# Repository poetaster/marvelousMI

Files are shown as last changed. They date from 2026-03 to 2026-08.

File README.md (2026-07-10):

## Introduction

marvelousMI is a fritzing project and PCB gerbers for a small desktop Mutable Instruments synth for use with the arduinoMI libraries. 

https://github.com/poetaster/arduinoMI

The 'marvelous' version is a eurorack version with slightly different ADC input handling (voltage dividers instead of diode clamps).

This is a basic circuit around an Olimex Pico2-xxl using a pcm5102 DAC for audio.

The firmware directory includes a complete synth with 3 parts:
* MI braids
* MI plaits
* MI rings

It's WIP but fully functional with midi and cv input.

More details and example audio and video can be found on my website at https://poetaster.org/marvelous

## Building with the arduino ide

I'm still using 1.8.19 because the behaviour of includes changed so much that it's easier just to stick to it. Some users have made adjustments to the lib to get them to compile, but the form in the repos is 1.8.19 compatible.

To build the ino you will need:

Into the arduino library context (on linux ~/Arduino/libraries) clone the individual modules:
https://github.com/poetaster/STMLIB
https://github.com/poetaster/PLAITS
https://github.com/poetaster/BRAIDS
https://github.com/poetaster/RINGS

In the STMLIB and PLAITS directories you will need to check out explicit branches:

git checkout plaits1.2 in both those directories.

You also need a couple of other libraries that you can install with the arduino ide:

Bounce2
pio_encoder
RotaryEncoder (I'm working with the raspberry pi guys on it).
Adafruit_SSD1306

with that done you should be able to compile / install directly to a marvelous or your own version thereof.

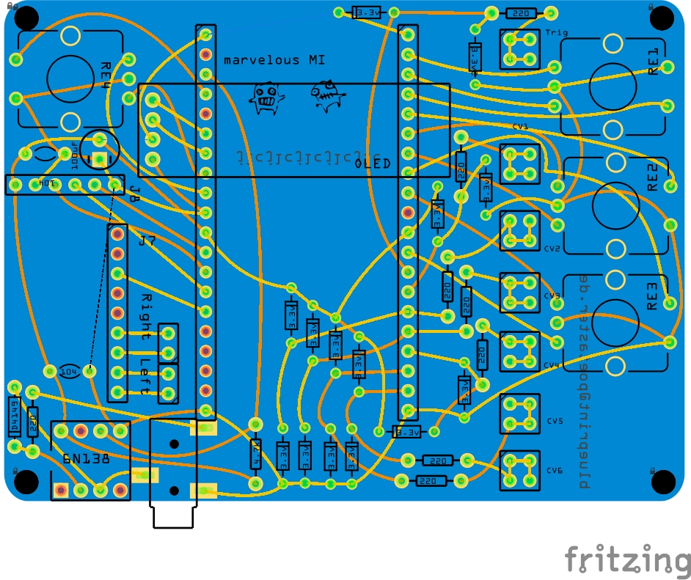
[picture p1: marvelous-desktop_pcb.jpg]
pcb view

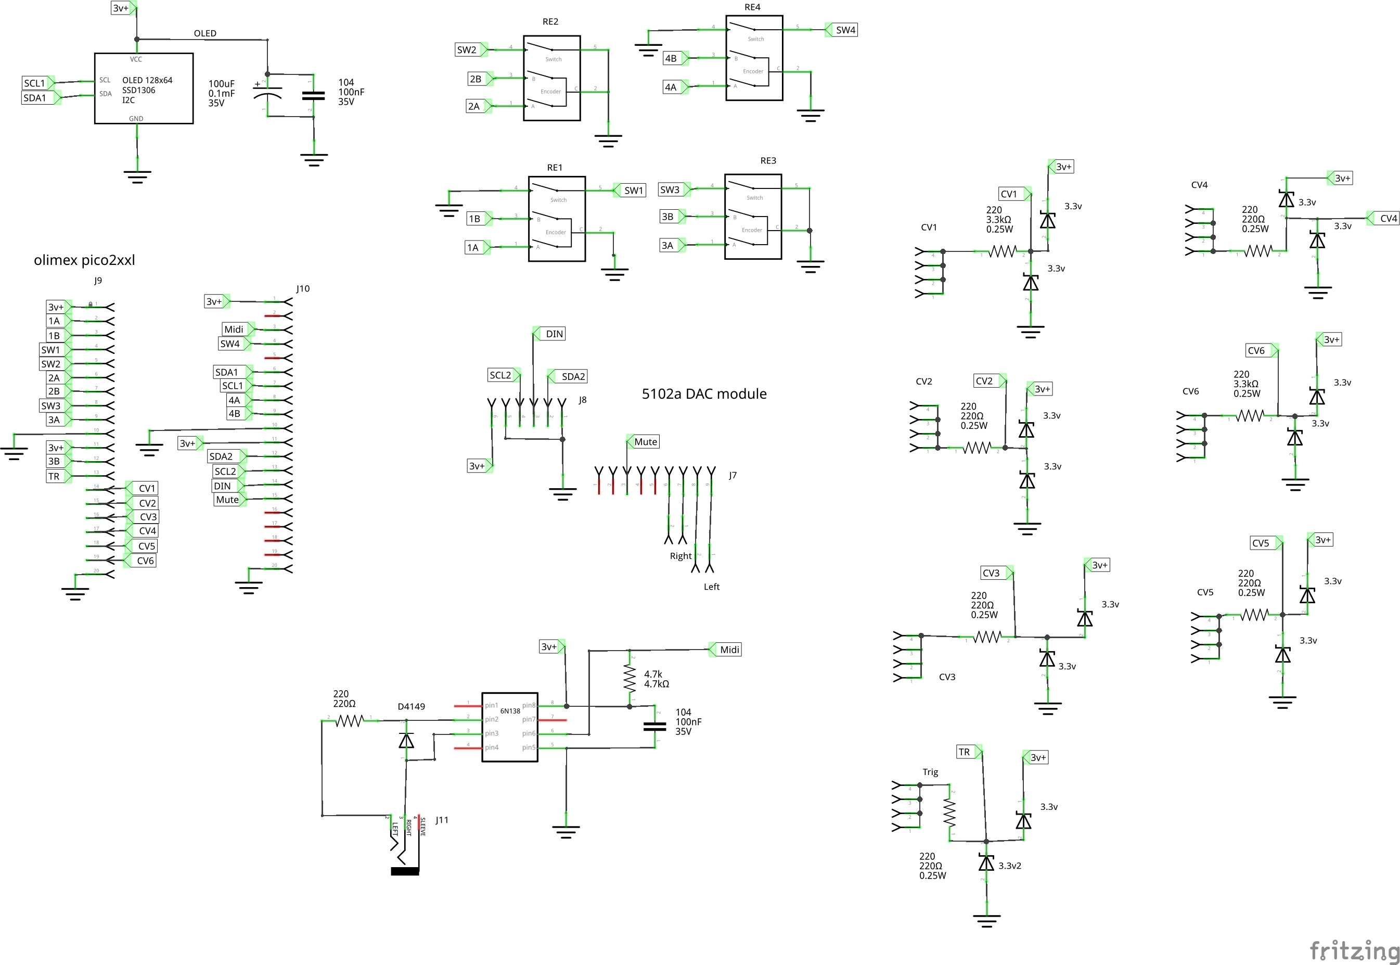
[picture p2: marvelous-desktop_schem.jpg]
schematic view


. I'm also on bigcartel at https://tonetoys.bigcartel.com/  and at https://tonetoys.etsy.com

## hardware notes.

Marvelous uses the XSMT pin of the PCM5102a for mute, which means a number od things need to be observed.
1. Do not solder the jumper H3L on the bottom of the board. It's connected. 
2. DO solder the other jumpers, H1,H2,H4 and take them all L (low).

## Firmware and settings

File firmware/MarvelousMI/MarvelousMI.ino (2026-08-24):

/*
  (c) 2024 blueprint@poetaster.de
  GPLv3

      Some sources, including the stmlib, rings, braids and plaits libs are
      MIT License Copyright (c)  2020 (emilie.o.gillet@gmail.com)
*/

bool debug = false;

#include <Arduino.h>
#include <math.h>
#include "stdio.h"
#include "pico/stdlib.h"
#include "hardware/gpio.h"
#include "hardware/sync.h"
#include <hardware/pwm.h>
#include <EEPROM.h>

#include <iostream>
#include <vector>
#include <algorithm>

#include <SoftwareSerial.h>

#include <MIDI.h>

//MIDI_CREATE_DEFAULT_INSTANCE();
// this method permits us to use arbitrary pins
// in pico land this is also a PIO statemachine (uart)

using Transport = MIDI_NAMESPACE::SerialMIDI<SoftwareSerial>;
int rxPin = 1;
int txPin = 3;
SoftwareSerial mySerial = SoftwareSerial(rxPin, txPin); //thruActivated
Transport serialMIDI(mySerial);
MIDI_NAMESPACE::MidiInterface<Transport> MIDI((Transport&)serialMIDI);


// start with CV input, switch on midi in or setting.
bool midi_switch = false;
bool midi_switch_setting = false;

#include <I2S.h>
#define SAMPLERATE 48000

#define pBCLK 8
#define pWS (pBCLK+1)
#define pDOUT 10
I2S DAC(OUTPUT, pBCLK, pDOUT);

// create ADSR env
#include "ADSR.h"
ADSR *env = new ADSR();
float envAttack;
float envDecay;
int envRelease;
float envSustain;
long envTimer = 0;



// utility
double randomDouble( double minf, double maxf) {
  return minf + random(1UL << 31) * (maxf - minf) / (1UL << 31);  // use 1ULL<<63 for max double values)
}

double median(std::vector<int>& numbers) {
  std::sort(numbers.begin(), numbers.end());
  int n = numbers.size();
  return n % 2 == 0 ? (numbers[n / 2 - 1] + numbers[n / 2]) / 2.0 : numbers[n / 2];
}

float mapf(float value, float fromLow, float fromHigh, float toLow, float toHigh) {
  float result;
  result = (value - fromLow) * (toHigh - toLow) / (fromHigh - fromLow) + toLow;
  return result;
}

int cv_avg = 3;
int16_t avg_cv(int cv_in) {

  //std::vector<int> data;
  int16_t val = 0;

  //for (int j = 0; j < cv_avg; ++j) data.push_back(analogRead(cv_in)); // val += analogRead(cv_in); // read the A/D a few times and average for a more stable value
  for (int j = 0; j < cv_avg; ++j) val += analogRead(cv_in); // read the A/D a few times and average for a more stable value
  val = val / cv_avg;

  //return median(data);

  return val;
}

/*
 *  set the globals to values from last saved voice parameters
 */

// volts to octave for 3.3 volts
// based on https://little-scale.blogspot.com/2018/05/pitch-cv-to-frequency-conversion-via.html
bool calibrating = false;
byte octaveTotal = 6;
byte octaveOffset = 0;
int voltage;

float data;
float pitch;
float pitch_offset = 0; // 36 in mmm 10volt input
float freq;

float max_voltage_of_adc = 3.3;
float voltage_division_ratio = 0.3333333333333;
float notes_per_octave = 12;
float volts_per_octave = 0.54;
float mapping_upper_limit = 4090; //60.0f; //(max_voltage_of_adc / voltage_division_ratio) * notes_per_octave * volts_per_octave;
float mapping_lower_limit = 5; //36.0f;


// trigger is on gp0

// cv input
#define CV1 (42u)
#define CV2 (43u)
#define CV3 (44u)
#define CV4 (45u)
#define CV5 (46u)
#define CV6 (47u)

int cv_ins[6] = {CV1, CV2, CV3, CV4, CV5, CV6};

// buffer for input to rings exciter
float CV1_buffer[32];

// button inputs
#define SW1 34
#define SW2 35
#define SW3 38
#define SW4 2

#include <Bounce2.h>
Bounce2::Button btn_one = Bounce2::Button();
Bounce2::Button btn_two = Bounce2::Button();
Bounce2::Button btn_four = Bounce2::Button();
Bounce2::Button btn_three = Bounce2::Button();

int btn_three_state = 0;
int btn_two_state = 0;
int btn_one_state = 0;

// Generic pin state variable
byte pinState;

// common output buffers
int16_t out_bufferL[32];
int16_t out_bufferR[32];

// sample buffer for clouds
int16_t sample_buffer[32]; // used while we play samples for demo

// voice params
int voice_number = 0; // for switching  between modules

float global_volume = 0.6;

// we are reusing the plaits nomenclature for all modules
// Plaits modulation vars
float morph_in = 0.5f; // IN(4);
float trigger_in = 0.0f; //IN(5);
float level_in = 0.0f; //IN(6);
float harm_in = 0.3f;
float timbre_in = 0.3f;
float position_in = 0.5f;
float pos_mod = 0.0f;

int engine_in;
char engine_name;
int bpm;
int selected_preset;

// persist plaits 
float plaits_morph = morph_in;
float plaits_harm = harm_in;
float plaits_timbre = timbre_in;
float plaits_position = position_in;
float plaits_level = 1.0f;
int   plaits_engine = 0;
// persist Rings 
float rings_position = 0.25f; // position
float rings_morph = morph_in;
float rings_harm = harm_in;
float rings_timbre = timbre_in;
float rings_level = 1.0f;
int   rings_engine = 0;
// persist braids
float braids_timbre = timbre_in;
float braids_morph = morph_in;
float braids_harm = harm_in;
float braids_position = position_in;
int   braids_engine = 0;
float braids_level = 1.0f;
// persist global
float fm_mod = 0.0f ; //IN(7);
float timb_mod = 0.0f; //IN(8);
float morph_mod = 0.0f; //IN(9);
float harm_mod = 0.0f; //IN(9);
float decay_in = 0.5f; // IN(10);
float lpg_in = 0.2f ;// IN(11);
float pitch_in = 32.0f;
int max_engines = 21; // varies per backend
// persist clouds
float clouds_morph = morph_in;
float clouds_timbre = timbre_in;
float clouds_harm = harm_in;
float clouds_position = position_in;
float clouds_mode = engine_in;
float clouds_dw_in = 1.0f;
float clouds_pos_in = 0.0f;
int   clouds_engine = 0;
float clouds_level = 1.0f;
bool  freeze_in = false;
int   voice_in = 4;

bool trigger_on = false;



#include <STMLIB.h> // 
#include <RINGS.h>
#include "rings.h"

#include <PLAITS.h>
#include "plaits.h"

#include <BRAIDS.h>
#include "braids.h"

// clouds dsp not used pushes ram
//#include <CLOUDS.h>
//#include "clouds.h"

#include "Midier.h"
// midi related functions
bool midi_busy = false;
#include "midi.h"

#include "names.h"

int device_initialized = 0 ; // used to identify if the eeprom has been written.
#include "eeprom.h"

bool writing = false;
bool reading = false;

const int encoderSW_pin = 28;

// encoder related // 2,3 8,9


// ugly, but using both ranges does not work
// this depends on poetasters version of the arduino library
#include "pio_encoder.h"
PioEncoder enc1(39, PIO pio1);
PioEncoder enc2(32, PIO pio1);
PioEncoder enc3(36, PIO pio1);

// PioEncoder enc4(6, PIO pio0);
// sadly we need a second approach.

#include <RotaryEncoder.h>
// Setup a RotaryEncoder without pio/ the meta: 6, 7 usually
RotaryEncoder enc4( 6,  7,  RotaryEncoder::LatchMode::FOUR3);

int enc1_pos_last = 0;
int enc1_delta = 0;
int enc2_pos_last = 0;
int enc2_delta = 0;
int enc3_pos_last = 0;
int enc3_delta = 0;
int enc4_pos_last = 0;
int enc4_delta = 0;


uint32_t enc1_push_millis;
uint32_t step_push_millis;
bool encoder_held = false;


// display related
const int oled_sda_pin = 4;
const int oled_scl_pin = 5;
const int oled_i2c_addr = 0x3C;
const int dw = 128;
const int dh = 32;

#include <Adafruit_SSD1306.h>
#define OLED_RESET     -1 // Reset pin # (or -1 if sharing Arduino reset pin)
#define SCREEN_ADDRESS 0x3C ///< See datasheet for Address; 0x3D for 128x64, 0x3C for 128x32
Adafruit_SSD1306 display(dw, dh, &Wire, OLED_RESET);

#include "font.h"
#include "helvnCB6pt7b.h"
#define myfont helvnCB6pt7b // Org_01 looks better but is small.
#define smallfont Org_01
#include "display.h"


// buttons & knobs defines/functions
//#include "control.h"


// audio related defines

int current_track;
int32_t update_timer;
int32_t button_timer;
int update_interval = 30;
int engineCount = 0;
bool button_state = true;

// last time btn_one release
unsigned long btnOneLastTime;
unsigned long btnTwoLastTime;
unsigned long btnFourLastTime;
int32_t previous_pitch = 40;

bool just_booting = true;

//File settingsFile;

// check all cv inputs and if none are changing,
// return false 

bool cv_connected(){

  bool connected = false;
  int cvs[6] = {0,0,0,0,0,0};

  // seed cv collection
  for (int j = 1; j < 6; ++j) {
      // collect cv for each input
      cvs[j] = analogRead(cv_ins[j]);
  }

  for (int i = 0; i < 10; i++) {
  // take 10 samples
    for (int j = 1; j < 6; j++) {
      if ( cvs[j] != analogRead(cv_ins[j]) ) {
          return true ;
      }
    }
  }
  return false;
}

void setup() {
  if (debug) {
    Serial.begin(57600);
    Serial.println(F("YUP"));
  }

  Serial.begin(31250);
  // start encoders MUST be first because of PIO init?
  //pio_set_gpio_base(PIO pio1, 16); this fails, do it in begin.
  //pio_set_gpio_base(PIO pio0, 0);

  enc1.begin();
  //enc1.flip(); // only on the green blue encoders
  enc2.begin();
  //enc2.flip(); // only on the green blue encoders
  enc3.begin();
  //enc3.flip(); // only on the green blue encoders

  delay(100);

  // set up Pico PWM audio output the DAC2 stereo approach works./
  DAC.setBuffers(4, 32); //plaits::kBlockSize * 4); // DMA buffers
  //DAC.onTransmit(cb);
  DAC.setFrequency(SAMPLERATE);
  // now start the dac
  DAC.begin();

  delay(100);


  // doesn't really get us anything
  analogReadResolution(12);

  // thi is to switch to PWM for power to avoid ripple noise
  pinMode(23, OUTPUT);
  digitalWrite(23, HIGH);

  // mute mute is LOW
  pinMode(11, OUTPUT);
  digitalWrite(11, HIGH);

  pinMode(LED_BUILTIN, OUTPUT);

  // CV
  pinMode(CV1, INPUT);
  pinMode(CV2, INPUT);
  pinMode(CV3, INPUT);
  pinMode(CV4, INPUT);
  pinMode(CV5, INPUT);
  pinMode(CV6, INPUT);
  // trigger in
  pinMode(41u, INPUT);

  // DISPLAY
  Wire.setSDA(oled_sda_pin);
  Wire.setSCL(oled_scl_pin);
  Wire.begin();
  // SSD1306 --  or SH1106 in this case
  if (!display.begin(SSD1306_SWITCHCAPVCC, oled_i2c_addr)) {
    //if (!display.begin( oled_i2c_addr)) {
    Serial.println(F("SSD1306 allocation failed"));
    //for (;;) ;  // Don't proceed, loop forever
  }

  displaySplash();

  // buttons

  btn_four.attach( SW4 , INPUT_PULLUP);
  btn_four.interval(5);
  btn_four.setPressedState(LOW);

  btn_one.attach( SW1 , INPUT_PULLUP);
  btn_one.interval(5);
  btn_one.setPressedState(LOW);

  btn_two.attach( SW2 , INPUT_PULLUP);
  btn_two.interval(5);
  btn_two.setPressedState(LOW);


  btn_three.attach( SW3 , INPUT_PULLUP);
  btn_three.interval(5);
  btn_three.setPressedState(LOW);

  // initialize envelope settings
  envAttack = 0.05f;
  envDecay = 0.3f;
  envRelease = 5;
  envSustain = 0.8f;
  env->setAttackRate(envAttack * SAMPLERATE);  // .01 second
  env->setDecayRate(envDecay * SAMPLERATE);
  env->setReleaseRate(envRelease * SAMPLERATE);
  env->setSustainLevel(envSustain);

  // initialize a mode to play
  //mode = midier::Mode::Ionian;
  //makeScale( roots[scaleRoot], mode);

  // init synth engines

  initPlaits();
  delay(50);
  initRings();
  delay(50);
  initBraids();
  // delay(100);
  //initClouds();

  // Initialize wave switch states
  update_timer = millis();
  button_timer = millis();

  // used to indicated we can fetch saved settings
  just_booting = true;
  EEPROM.begin(2048);
  delay(150);

  if (just_booting) {
    loadInit();
    if (device_initialized == 1 ) {
      // only one for now 
      //loadLastPreset(); // sets selected_preset from base eeprom save point
      loadMemorySlots();
    } else {
      // first use of device, so prep it.
      selected_preset = 0;
      currentConfig = defaultSlots[0]; // current config is default 0
      initializeEEPROM(); // first run, get settings into all 8 slots
      //bpm = currentConfig.tempo;
      //internalClock = currentConfig.internalClock;
      writeInit(); // set flag for next boot
    }

    just_booting = false;
  }

  // set up midi last, debugging
  MIDI.setHandleNoteOn(HandleMidiNoteOn);  // Put only the name of the function
  MIDI.setHandleNoteOff(HandleMidiNoteOff);  // Put only the name of the function
  MIDI.setHandleControlChange(HandleControlChange);  // Put only the name of the function
  // Initiate MIDI communications, listen to all channels (not needed with Teensy usbMIDI)
  MIDI.begin(MIDI_CHANNEL_OMNI);

  /*
  int sensorValue;

  // calibrate note in CV1
  while (millis() < 5000) {
    sensorValue = analogRead(CV1);

    // record the maximum sensor value
    if (sensorValue > mapping_upper_limit) {
      mapping_upper_limit = sensorValue;
    }

    // record the minimum sensor value
    if (sensorValue < mapping_lower_limit) {all tabs to spaces
      mapping_lower_limit = sensorValue;
    }
  }
  */

}

// main loop for audio rendering
void loop() {

  if ( DAC.availableForWrite()) {
    if ( ! writing && ! midi_busy) {
      if (voice_number == 0) {
        updatePlaitsAudio();
        // now apply the envelope
        for (size_t i = 0; i < plaits::kBlockSize; ++i) {
          int16_t sampleL = (int16_t) ( (float) outputPlaits[i].out * env->process() * global_volume) ;
          int16_t sampleR = (int16_t) ( (float) outputPlaits[i].aux * env->process() * global_volume) ;
          //out_bufferL[i] = sample;
          DAC.write( sampleL );
          DAC.write( sampleR );
        }

      } else if (voice_number == 1) {
        // we're not doing stereo because we get neat poly output with note ins like this
        // global volume is in the update method
        updateRingsAudio();
        for (size_t i = 0; i < 32; i++) {
          DAC.write( out_bufferL[i] );
          DAC.write( out_bufferL[i] );
        }

      } else if (voice_number == 2) {
        // just mono for now
        updateBraidsAudio();
        // braids is louder so take it down a notch
        for (size_t i = 0; i < 32; i++) {
          int16_t sample =   (int16_t) ( (float) inst[0].pd.buffer[i] * env->process() * ( global_volume - 0.3f ) ) ;
          DAC.write( sample );
          DAC.write( sample );
        }
      } 

     /*  does not run on the olimex
      else if (voice_number == 3) {
        // clouds, samplebuffer at same time
        // or braids into buffer directly.
        DAC.setFrequency(32000);
        updateBraidsAudio();
        // copy the braids audio to the clouds input buffer
        clouds::FloatFrame  *input = cloud[0].input;
        for (int i = 0; i < 32; i++) {
          float sample;
          sample = (float) ( analogRead(CV6) ) ;
          if (sample < 150.0f) {
            sample = (float) ( inst[0].pd.buffer[i] / 32768.0f  ) ;
          }
          input[i].l = sample;
          input[i].r = sample;  // Mono input
        }
        updateCloudsAudio();
        clouds::FloatFrame  *output = cloud[0].output;
        for (int i = 0; i < 32; i++) {
          int16_t sampleL =  stmlib::Clip16( static_cast<int32_t>(  (  output[i].l )  * 32768.0f  ) * 1.5f ) ;
          int16_t sampleR =  stmlib::Clip16( static_cast<int32_t>(  (  output[i].r )  * 32768.0f  ) * 1.5f ) ;
          DAC.write( sampleL );
          DAC.write( sampleR );
        }
      }
      */
      } // end writing
   } // end available for write

}

void setup1() {
  delay (1000); // wait for main core to start up perhipherals
}

// second core deals with ui / control rate updates
void loop1() {

  if (! writing) { // don't do shit when eeprom is being written1.00
    // we need these on boot so the second loop can catch the startup button.
    btn_one.update();
    btn_two.update();
    btn_three.update();
    btn_four.update();

    unsigned long now = millis();

    // first control elements
    if (voice_number == 0) {
      updatePlaitsControl();
    } else if (voice_number == 1) {
      updateRingsControl();
    }
    // need faster updates
    read_encoders();

    if ( midi_switch == false && midi_switch_setting == false ) {
      // no midi and we have cv input
      //if ( cv_connected() ) {
        voct_midi(CV1);
      //}
    }
    read_trigger();

    MIDI.read();

    if ( now - update_timer > 5 ) {

      // only read cvs if at least one has input
      if ( cv_connected() == true) {
        read_cv();
      }

      read_buttons();

      // display updates
      if (btn_two_state == 1) {
        displayADSR();
      } else {
        if (voice_number == 0) {
          displayPlaits();
        } else if (voice_number == 1) {
          displayRings();
        } else if (voice_number == 2) {
          displayBraids();
        } else {
          displayClouds();
        }
      }
      update_timer = now;
    }
  }
}

/*
 *  set the globals to values from last saved voice parameters
 */
void setVoiceParameters(){
  if (voice_number == 0) {
      engine_in = plaits_engine; // engine_in % 17;
      max_engines = 21;
      morph_in = plaits_morph;
      timbre_in = plaits_timbre;
      harm_in = plaits_harm;
      position_in = plaits_position;

    } else if (voice_number == 1) {
      engine_in = rings_engine;
      max_engines = 5;
      morph_in = rings_morph;
      harm_in = rings_harm;
      timbre_in = rings_timbre;
      position_in = rings_position;

    } else if (voice_number == 2 ) {
      engine_in = braids_engine;
      max_engines = 45;
      morph_in = braids_morph;
      timbre_in = braids_timbre;

    } else if (voice_number == 3 ) {
      engine_in = clouds_engine;
      max_engines = 3;
      morph_in = clouds_morph;
      timbre_in = clouds_timbre;
      harm_in = clouds_harm;
    }
}

void read_buttons() {

  bool doublePressMode = false;
  bool longPress = false;
  int oneState = btn_one.read();
  int twoState = btn_two.read();
  int fourState = btn_four.read();

  // we toggle button three for either position or timber encoder action
  if ( btn_three.pressed() ) {
      btn_three_state = !btn_three_state;
  }
  // we toggle button two state for either  adsr or normal parameters
  if ( btn_two.pressed() ) {
      btn_two_state = !btn_two_state;
  }

  // if button one was held for more than 300 millis and we're in rings toggle easteregg
  if ( btn_one.rose() ) {

    btnOneLastTime = btn_one.previousDuration();
    if ( btnOneLastTime > 350 && ! btn_two.pressed()) {
      if ( voice_number == 1 ) {
        easterEgg = !easterEgg;
        longPress = true;
      }
      // clouds, not used
      if ( voice_number == 3 && ! btn_two.pressed()) {
        freeze_in = !freeze_in;
        longPress = true;
      }
    } else if (btnOneLastTime < 350 ) {
      btn_one_state = !btn_one_state;
    }
  }

  // meta button pressed to cycle through voices
  if (btn_four.rose()) {
    // first record our last settings
    if (voice_number == 0) {
      plaits_morph = morph_in;
      plaits_timbre = timbre_in;
      plaits_harm = harm_in;
      plaits_engine = engine_in;
      plaits_position = position_in;
    }
    if (voice_number == 1) {
      rings_morph = morph_in;
      rings_timbre = timbre_in;
      rings_harm = harm_in;
      rings_position = position_in;
      rings_engine = engine_in;
    }
    if (voice_number == 2) {
      braids_morph = morph_in;
      braids_timbre = timbre_in;
      braids_engine = engine_in;
    }
    /* not used */
    if (voice_number == 3) {
      clouds_morph = morph_in;
      clouds_timbre = timbre_in;
      clouds_harm = harm_in;
      clouds_position = position_in;
      clouds_engine = engine_in;
    }

    voice_number++;
    if (voice_number > 2) voice_number = 0;

    // Save to eeprom
    // set mute then save
    // send null data for (21ms @ 48kHz)

    writing = true;
    digitalWrite(11, HIGH);
    digitalWrite(11, LOW);
    int16_t sampleL = 0;
    unsigned long now = millis();

    while ( millis() - now < 35) {
        DAC.write(sampleL);
        DAC.write(sampleL);
    }
    delay(21);

    saveToEEPROM(0);
    setVoiceParameters();

    delay(1);
    digitalWrite(11, LOW);
    digitalWrite(11, HIGH);
    writing = false;
  }

  if (!doublePressMode && !longPress) {
    // being tripple shure :)

  }
}


float voct_midiBraids(int cv_in) {
  int val = 0;
  for (int j = 0; j < cv_avg; ++j) val += analogRead(cv_in); // read the A/D a few times and average for a more stable value
  val = val / cv_avg;
  pitch = pitch_offset + map(val, 0.0, 4095.0, mapping_upper_limit, 0.0); // convert pitch CV data value to a MIDI note number
  return pitch - 37; // don't know why, probably tuned to A so -5 + -36 to drop two octaves
}


void voct_midi(int cv_in) {
  int val = 0;
  for (int j = 0; j < 15; ++j) val += analogRead(cv_in); // read the A/D a few times and average for a more stable value
  val = val / 15;
  // data = (float) val * 1.0f;
  pitch = map(val, mapping_lower_limit, mapping_upper_limit, 36, 84); // convert pitch CV data value to a MIDI note number

  //pitch = pitch - pitch_offset;

  pitch_in = pitch;

  // this is a temporary move to get around clicking on trigger + note cv in
  if (pitch != previous_pitch) {
    previous_pitch = pitch;
    // this is the plaits version

  }
}

// in marvelous, moved to digital pin tx/gp0
void read_trigger() {
  int16_t trig ;
  for (int j = 0; j < 5; ++j) trig += analogRead(41u); // read the A/D a few times and average for a more stable value
  trig = trig / 5 ;

  if ( midi_switch == false && midi_switch_setting == false ) {
    if (trig  > 3000 && ! trigger_on ) {
      trigger_in = 1.0f;
      trigger_on = true;
      //if (millis() - envTimer > 50) {
      envTimer = millis();
      env->gate(true);
      //}
    } else {
      //don't turn off here?
      trigger_in = 0.0f;
      // don't retrigger ADSR too quickly
      //if (millis() - envTimer > 50) {
      envTimer = 0;
      env->gate(false);
      //}
      trigger_on = false;
    }
    if (voice_number == 0) updateVoicetrigger();

  }

}
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

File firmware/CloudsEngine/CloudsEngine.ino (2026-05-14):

/*
  (c) 2025 blueprint@poetaster.de
  GPLv3 the libraries are MIT as the originals for STM from MI were also MIT.

  Change the PWMOUT number to the pin you are doing pwm on.
  Works fine 200mHz -O2 on an RP2350

  BE CAREFULL, can be loud or high pitched. Or BOTH!

*/

bool debugging = true;

#include <Arduino.h>
#include "stdio.h"
#include "pico/stdlib.h"
#include "hardware/sync.h"
#include <hardware/pwm.h>

#include <I2S.h>
#define SAMPLERATE 48000

#define pBCLK 8
#define pWS (pBCLK+1)
#define pDOUT 10
I2S DAC(OUTPUT, pBCLK, pDOUT);

// we can refer to sample[0] since there is only one.
#define NUM_VOICES 3
struct voice_t {
  int16_t sample;   // index of the sample structure in sampledefs.h
  int16_t level;   // 0-1000 for legacy reasons
  uint32_t sampleindex; // 20:12 fixed point index into the sample array
  uint16_t sampleincrement; // 1:12 fixed point sample step for pitch changes
  bool isPlaying;  // true when sample is playing
} voice[NUM_VOICES] = {
  0, 700, 0, 4096, false, // test sample
  1, 700, 0, 4096, false, // test sample
  2, 700, 0, 4096, false, // test sample
};
#include "samples.h" // we're just using a sample for now.
#define NUM_SAMPLES (sizeof(sample)/sizeof(sample_t))


// plaits dsp
#include <STMLIB.h>
#include <CLOUDS.h>

// the following is largely from the mi-Ugens sourc MiClouds.cpp
#include "clouds/dsp/granular_processor.h"
#include "clouds/resources.h"
#include "clouds/dsp/audio_buffer.h"
#include "clouds/dsp/mu_law.h"
#include "clouds/dsp/sample_rate_converter.h"



const uint16_t kAudioBlockSize = 32;        // sig vs can't be smaller than this!
const uint16_t kNumArgs = 14;


enum ModParams {
  PARAM_PITCH,
  PARAM_POSITION,
  PARAM_SIZE,
  PARAM_DENSITY,
  PARAM_TEXTURE,
  PARAM_DRYWET,
  PARAM_CHANNEL_LAST
};

// main output audio buffer
int16_t out_bufferL[32];
int16_t out_bufferR[32];

int16_t sample_buffer[32]; // used while we play samples for demo


struct Unit {

  clouds::GranularProcessor   *processor;

  // buffers
  //uint8_t     *large_buffer;
  //uint8_t     *small_buffer;
  // Pre-allocate big blocks in main memory and CCM. No malloc here.
  uint8_t     large_buffer[118784];
  uint8_t     small_buffer[65536 - 128];

  // parameters
  float       in_gain;
  bool        freeze;
  bool        trigger, previous_trig;
  bool        gate;

  float       pot_value_[PARAM_CHANNEL_LAST];
  float       smoothed_value_[PARAM_CHANNEL_LAST];
  float       coef;      // smoothing coefficient for parameter changes

  clouds::FloatFrame  input[kAudioBlockSize];
  clouds::FloatFrame  output[kAudioBlockSize];

  float       sr;
  long        sigvs;

  bool        gate_connected;
  bool        trig_connected;
  uint32_t      pcount;


  clouds::SampleRateConverter < -clouds::kDownsamplingFactor, 45, clouds::src_filter_1x_2_45 > src_down_;
  clouds::SampleRateConverter < +clouds::kDownsamplingFactor, 45, clouds::src_filter_1x_2_45 > src_up_;

};

struct Unit cloud[1];

// Plaits modulation vars
float morph_in = 0.1f; // IN(4);
float trigger_in = 0.0f; //IN(5);
float level_in = 0.5f; //IN(6);
float harm_in = 0.1f;
float timbre_in = 0.1f;
int engine_in;

float fm_mod = 0.f ; //IN(7);
float timb_mod = 0.f; //IN(8);
float morph_mod = 0.f; //IN(9);
float decay_in = 0.5f; // IN(10);
float lpg_in = 0.2f ;// IN(11);
float pitch_in = 60.f;
float octave_in = 3.f;
float dw_in = 0.5f;
float pos_in = 0.0f;
bool freeze_in = false;
int voice_in = 1;
int mode_in = 0;

int engineCount = 0;
int engineInc = 0;

// clock timer  stuff  

#define TIMER_INTERRUPT_DEBUG         0
#define _TIMERINTERRUPT_LOGLEVEL_     4

// Can be included as many times as necessary, without `Multiple Definitions` Linker Error
#include "RPi_Pico_TimerInterrupt.h"

//unsigned int SWPin = CLOCKIN;

#define TIMER0_INTERVAL_MS  20.833333333333
//24.390243902439025 // 44.1
// \20.833333333333running at 48Khz

#define DEBOUNCING_INTERVAL_MS   2// 80
#define LOCAL_DEBUG              0

volatile int counter = 0;

// Init RPI_PICO_Timer, can use any from 0-15 pseudo-hardware timers
RPI_PICO_Timer ITimer0(0);

bool TimerHandler0(struct repeating_timer *t) {
  (void) t;
  bool sync = true;
  if ( DAC.availableForWrite()) {
    for (size_t i = 0; i < kAudioBlockSize; i++) {
      DAC.write( out_bufferL[i] );
      DAC.write( out_bufferR[i] );
    }
    counter = 1;
  }

  return true;
}

float mapf(float value, float fromLow, float fromHigh, float toLow, float toHigh) {
  float result;
  result = (value - fromLow) * (toHigh - toLow) / (fromHigh - fromLow) + toLow;
  return result;
}

// produce some random numbers in ranges.
double randomDouble(double minf, double maxf)
{
  return minf + random(1UL << 31) * (maxf - minf) / (1UL << 31);  // use 1ULL<<63 for max double values)
}

// audio related defines
//float freqs[12] = { 261.63f, 277.18f, 293.66f, 311.13f, 329.63f, 349.23f, 369.99f, 392.00f, 415.30f, 440.00f, 466.16f, 493.88f};
float freqs[12] = { 42.f, 44.f, 46.f, 48.f, 49.f, 50.f, 51.f, 53.f, 54.f, 55.f, 56.f, 57.f};

int carrier_freq;

void setup() {
  if (debugging) {
    Serial.begin(115200);
    Serial.println(F("YUP"));
  }
  // pwm timing setup
  // we're using a pseudo interrupt for the render callback since internal dac callbacks crash
  // comment the following block out and uncomment the DAC.onTransmit(cb) line to use the DAC callback method

  if (ITimer0.attachInterruptInterval(TIMER0_INTERVAL_MS, TimerHandler0)) // that's 48kHz
  {
    if (debugging) Serial.print(F("Starting  ITimer0 OK, millis() = ")); Serial.println(millis());
  }  else {
    if (debugging) Serial.println(F("Can't set ITimer0. Select another freq. or timer"));
  }


  // set up Pico PWM audio output
  DAC.setBuffers(4, 32); // DMA buffers
  //DAC.onTransmit(cb);
  DAC.setFrequency(SAMPLERATE);
  DAC.begin();

  // thi is to switch to PWM for power to avoid ripple noise
  pinMode(23, OUTPUT);
  digitalWrite(23, HIGH);
  // start playing sample
  voice[0].sampleindex = 0; // trigger sample for this track
  voice[0].isPlaying = true;

  fillSampleBuffer();
  // init the clouds voice(s)
  initVoices();
  updateCloudsAudio();

}
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

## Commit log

2026-01-07 Add: initial fritzing file addition
    [MMM.fzz, marvelous-desktop.fzz]
2026-01-07 Fix: correct text sizing, hole spacing
    [marvelous-desktop.fzz]
2026-01-07 Add: gerbers and svgs for boards
    [marvelous-desktop-top_contour.gm1, marvelous-desktop-top_copperBottom.gbl, marvelous-desktop-top_copperTop.gtl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]
2026-02-09 [Fix] missing 3.3volt supply to optocoupler
    [marvelous-desktop.fzz]
2026-02-17 [Error] the is the erroneous input version
    [marvelous-desktop.fzz]
2026-02-17 [Fix] the is the current top plate
    [marvelous-desktop-top.fzz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]
2026-02-17 [Add] start a new version with correct dividers
    [marvelous-desktop-2.fzz]
2026-03-10 [Add] update firmware note last version of fzz
    [marvelous-desktop.fzz]
2026-03-12 [Fix] correct eeprom methods and adapt voice change methods
    [MarvelousMI.ino, eeprom.h]
2026-03-12 [Fix] correct the latching of the meta encoder. correct the increments of the other encoders
    [MarvelousMI.ino]
2026-03-12 [Fix] display updates. spacing, consistent font face
    [display.h]
2026-03-15 [Add] button 3, encoder three toggle timbre or position change via encoder
2026-03-16 [Refactor] diode clamp layout
    [marvelous-desktop.fzz]
2026-03-16 [Add] current gerbers for the diode clamp version
    [marvelous-desktop-top_contour.gm1, marvelous-desktop_copperBottom.gbl, marvelous-desktop_copperTop.gtl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]
2026-03-17 [Add] latest gerbers
    [marvelous-desktop.fzz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]
2026-03-17 [Fix] correct display of adsr
    [MarvelousMI.ino, display.h]
2026-05-02 [Revert] take clouds out of this version
    [MarvelousMI.ino, clouds.h]
2026-05-02 [Add] reverb, fb, spread, dw to display and encoders
2026-05-11 [Fix] add global volume, correct midi CC updates
    [MarvelousMI.ino, display.h, midi.h]
2026-05-11 [Fix] correct input threshold for trigger add optional cv input check
    [MarvelousMI.ino]
2026-05-14 [Fix] missing traces on cv inputs and midi in ground
    [marvelous-desktop.fzz]
2026-05-14 [fix] cv placement and values
    [MMM.fzz]
2026-05-14 [Fix] minor cv adjust
    [marvelous-desktop.fzz]
2026-05-19 [Fix] shift CV inputs, adjust gain in rings, adjust cv6 acquire for exciter
    [MarvelousMI.ino, display.h]
2026-05-19 [Refactor] move to divider with load circuit (3.3 or 4.7)
    [MMM.fzz]
2026-05-20 [DRC] check passed, layout done
    [MMM.fzz]
2026-05-20 [Fix] switch on enc 3. spacing of pcm bins
    [MMM-top.fzz, MMM.fzz]
2026-05-26 [Release] last version after jlc prototype one of marvelous eurorack
    [MMM-top.fzz, MMM.fzz, marvelous-desktop.fzz]
2026-06-13 [Fix] correct encoder pin assignments and buttons
    [MarvelousEuro.ino]
2026-06-14 [Fix] pin assignments, cv offsets, cv-midi
    [MarvelousEuro.ino, display.h]
2026-06-14 [Fix] compensate on octaves below and above 2/3 for non-linear voltage
    [MarvelousEuro.ino]
2026-06-16 [Fix] various button and encoder function assignments
    [MMM.fzz]
2026-06-18 [Add] calibration display and functions
2026-06-19 [Add] working gerbers
    [MMM-top_contour.gm1, MMM-top_copperBottom.gbl, MMM-top_copperTop.gtl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]
2026-06-21 [Fix] layout of faceplate
    [MMM-top.fzz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]
2026-06-21 [rename] correct naming
    [marvelous-top.fzz, marvelous.fzz]
2026-07-06 * add cv calibration data to eeprom settings * correct the on boot button logic to avoid booting into calibration of easter egg mode * remove unused methods from eeprom
    [MarvelousEuro.ino, display.h, eeprom.h]
2026-07-06 * minor correction to the variance at which new pitch and cv in averaging
    [MarvelousEuro.ino]
2026-07-06 [Fix] remove uneeded methods and call which could be destructive
    [eeprom.h]
2026-07-09 * add global volume to eeprom * set the encoders used for global volume and position to B/C * adjust CV input range.
2026-07-10 [Add] bournes define to flip encoders, fine tune start display, adsr a encoder increment
    [MarvelousEuro.ino, display.h]
2026-08-24 [Fix] correct button assignment / encoder action for btn2/3 global volume/position
    [MarvelousMI.ino, midi.h]
2026-08-24 [Fix] add some checks for busy midi and set baudrate
    [MarvelousMI.ino, midi.h]
